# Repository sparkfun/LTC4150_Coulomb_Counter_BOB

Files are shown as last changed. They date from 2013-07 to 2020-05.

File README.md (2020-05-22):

SparkFun Coulomb Counter Breakout - LTC4150
===========================

SparkFun Coulomb Counter Breakout - LTC4150 (https://www.sparkfun.com/products/12052)

_[SparkFun Coulomb Counter Breakout - LTC4150 [ BOB-12052 ]](https://www.sparkfun.com/products/12052)_

*Breakout board for the Linear Tech LTC4150 Coulomb Counter (bidirectional current sensor / battery gauge)*

The LTC4150 Coulomb Counter monitors current passing through it (from the IN header or JST connector to the OUT header). Each time 0.1707 mAh passes through the device, the INT pin will pulse low. Or to put it another way, the INT pin will pulse low 5859 times for each Ah that passes through it.

There is also a POL pin that you can check each time INT goes low. POL will be L for current going from IN to OUT, and H for current going from OUT to IN (battery charging).

If you count these pulses and add or subtract from a total depending on the POL signal, you can keep accurate track of the state of a battery connected to the board.

The Coulomb Counter can accommodate power supplies up to 8.5V and up to 1A.

Quickstart (Arduino)
-------------------

* Configure the jumpers:

    If you're connecting the Coulomb Counter to a 5V system, leave solder jumpers SJ2 and SJ3 (on the bottom of the board) open (the default).

    If you're connecting the Coulomb Counter to a 3.3V system, close both SJ2 and SJ3.

* Hook up the I/O lines:

    Connect VIO to your system's VCC (3.3V or 5V) line.

    Connect GND to your system's ground line.

    Connect INT to your system's interrupt input (D3)

    Connect POL to an I/O pin (D4)

* Connect the IN header or the JST connector to your power source (up to 8.5V)

* Connect the OUT header to your system's power input

* Upload and run the Coulomb_Interrupt example code from this repository, and open a Serial Monitor set to 9600 bps. It should display a hello message and begin giving you periodic updates about the battery state. (See the comments for instructions on customizing it for your exact battery.)

See the [Hookup Guide](https://learn.sparkfun.com/tutorials/ltc4150-coulomb-counter-hookup-guide) for much more information.

Have fun! -Your friends at SparkFun

Repository Contents
-------------------

* **/Documentation** - Data sheets, additional product information
* **/Hardware** - Eagle design files (.brd, .sch)
* **/Production** - Production panel files (.brd)
* **/Software** - Arduino example code

Documentation
--------------

* **[Hookup Guide](https://learn.sparkfun.com/tutorials/ltc4150-coulomb-counter-hookup-guide)** - Basic hookup guide

License Information
-------------------

This product is _**open source**_! 

Please review the LICENSE.md file for license information. 

If you have any questions or concerns on licensing, please contact technical support on our [SparkFun forums](https://forum.sparkfun.com/viewforum.php?f=152).

Distributed as-is; no warranty is given.

- Your friends at SparkFun.

_<COLLABORATION CREDIT>_

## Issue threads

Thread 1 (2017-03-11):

Invalid library found

AusUser5, 2017-03-11:
Adding the zip to Ardunino 1.6.11 failed.

Adding library manually showed error "invalid library found"

bboyho, 2020-05-22:
Hi,

Sorry for the delay in reply. I came across your question when browsing our issues. It looks like you are trying to add the example code to your Arduino library. I do not believe that will work (as you have seen) because the example code is not structured as a library.

If you are still wondering, you just need to unzip the files and open the individual &#42;.ino examples in the Arduino IDE.

Closed 2020-05-22.

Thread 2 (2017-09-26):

Interrupt example code doesn't work on Pro Micro

chrise96, 2017-09-26:

mgrusin, 2017-10-18:
Hi there, did you solve your issue? If you found the solution, it's good karma to post it here for us (and others) to see. Thanks!

chrise96, 2017-10-18:
Hi Mike,
I haven't figured this issue out yet. I'm happy you are still active! I cant make this one open but made some edits to the post.

The issue is that the interrupt example takes a long time to show an interrupt message and gives me incorrect values of mA:
Normal with polling:
mAh: 1998.98 soc: 99.95% time: 367.73s mA: 1.67
mAh: 1998.81 soc: 99.94% time: 374.93s mA: 1.64
mAh: 1998.63 soc: 99.93% time: 363.59s mA: 1.69

With interrupt example (with same external microcontroller and external battery connected):
mAh: 1998.98 soc: 99.95% time: 1267.73s mA: 0.30 (something like this, dont have the log)
mAh: 1998.81 soc: 99.94% time: 1274.93s mA: 0.30 (something like this, dont have the log)

Closed 2017-10-18.

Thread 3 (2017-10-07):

multiple invalid libraries found

joebataz, 2017-10-07:

joebataz, 2017-10-07:
I am getting a long list of invalid library found in <path to arduino libraries> I  have just started up programming (or trying to) again after a couple of years. I am also getting
Documents/Arduino/libraries/FastLED/FastLED.h:12:2: warning: #warning FastLED version 3.001.000 (Not really a warning, just telling you here.) [-Wcpp]
 #warning FastLED version 3.001.000  (Not really a warning, just telling you here.)
I don't understand if this is an error or not. How do I get rid of these errors/warnings/whatever?

THANKS to whoever gets me this answer, I REALLY appreciate it!
joe b

mgrusin, 2017-10-09:
If you haven't used it in a while, recent updates to Arduino may have rendered old libraries invalid. I would try opening sketch/include library/manage libraries, and see if any of them can be automatically updated. If they can't you may have to delete them and reinstall them manually. If you're stuck, our tech support department can help: https://www.sparkfun.com/technical_assistance. Hope this helps, good luck!

joebataz, 2017-10-09:
Thanks Mike.
It resolved down to 5 problem libraries and one bad nano. Got new libraries where needed and fired up old reliable Mega and all is well now. Did a little refresher coding and looks like I actually remember how to code!

Thanks again!!

Joe B
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

mgrusin, 2017-10-09:
That's GREAT to hear! Have fun and let us know if you have further questions (or want to show off what you're making! ;)

Closed 2017-10-09.

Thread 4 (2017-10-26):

Three Coulomb counters with all different values

arrowmax08, 2017-10-26:
Hi,

I tested three LTC4150's that all print different values.

The first value will be incorrect, because we have no previous start time to compare the delay between interrupts with. The INT pin will pulse low every time 0.614 coulombs passes through the device. So you can say that all coulomb counters with the same setup must print very similar values.

With two AA batteries connected to the IN port of the Coulomb counter I get around the following values:

Coulomb counter 1: prints "1.30 mA"
Coulomb counter 2: prints "2.15 mA"
Coulomb counter 3: prints "1.80 mA"

Are they not calibrated right?

mgrusin, 2017-10-26:
Good question and interesting results.

To be honest, determining instantaneous power consumption from the timing of the coulomb interrupt, especially for low currents like the above, is a bit of a parlor trick. Even though the number of INT pulses over time should be accurate, calculating instantaneous power consumption by measuring the time between them is subject to numerous measurement and rounding errors (especially if you're using the polled code rather than interrupt-driven). Your test setup is also important; it's better to measure a fixed resistor (the same one for all three boards) than a dynamic load like a processor or LED; and to use a fixed linear power source rather than a battery, which can change voltage during use and recovery. And you're right; I've never looked at the statistics for a large number of counters, but there could be manufacturing variations in the chips and sense resistors, etc.

 If you absolutely require consistent numbers between all your boards, the best solution is always to calibrate them individually using the best test setup you can manage. This usually means a fixed (linear) power source and load resistor.  Per the above I'd measure a large number of INT pulses over time rather than the individual timing. You'd then apply the results to the individual bits of software doing the reading. This is often not worth the trouble for a few percent difference, but if one or more of your boards is obviously misbehaving please do contact our tech support department for replacement.

Hope this helps, thanks for asking!

Closed 2018-07-06.

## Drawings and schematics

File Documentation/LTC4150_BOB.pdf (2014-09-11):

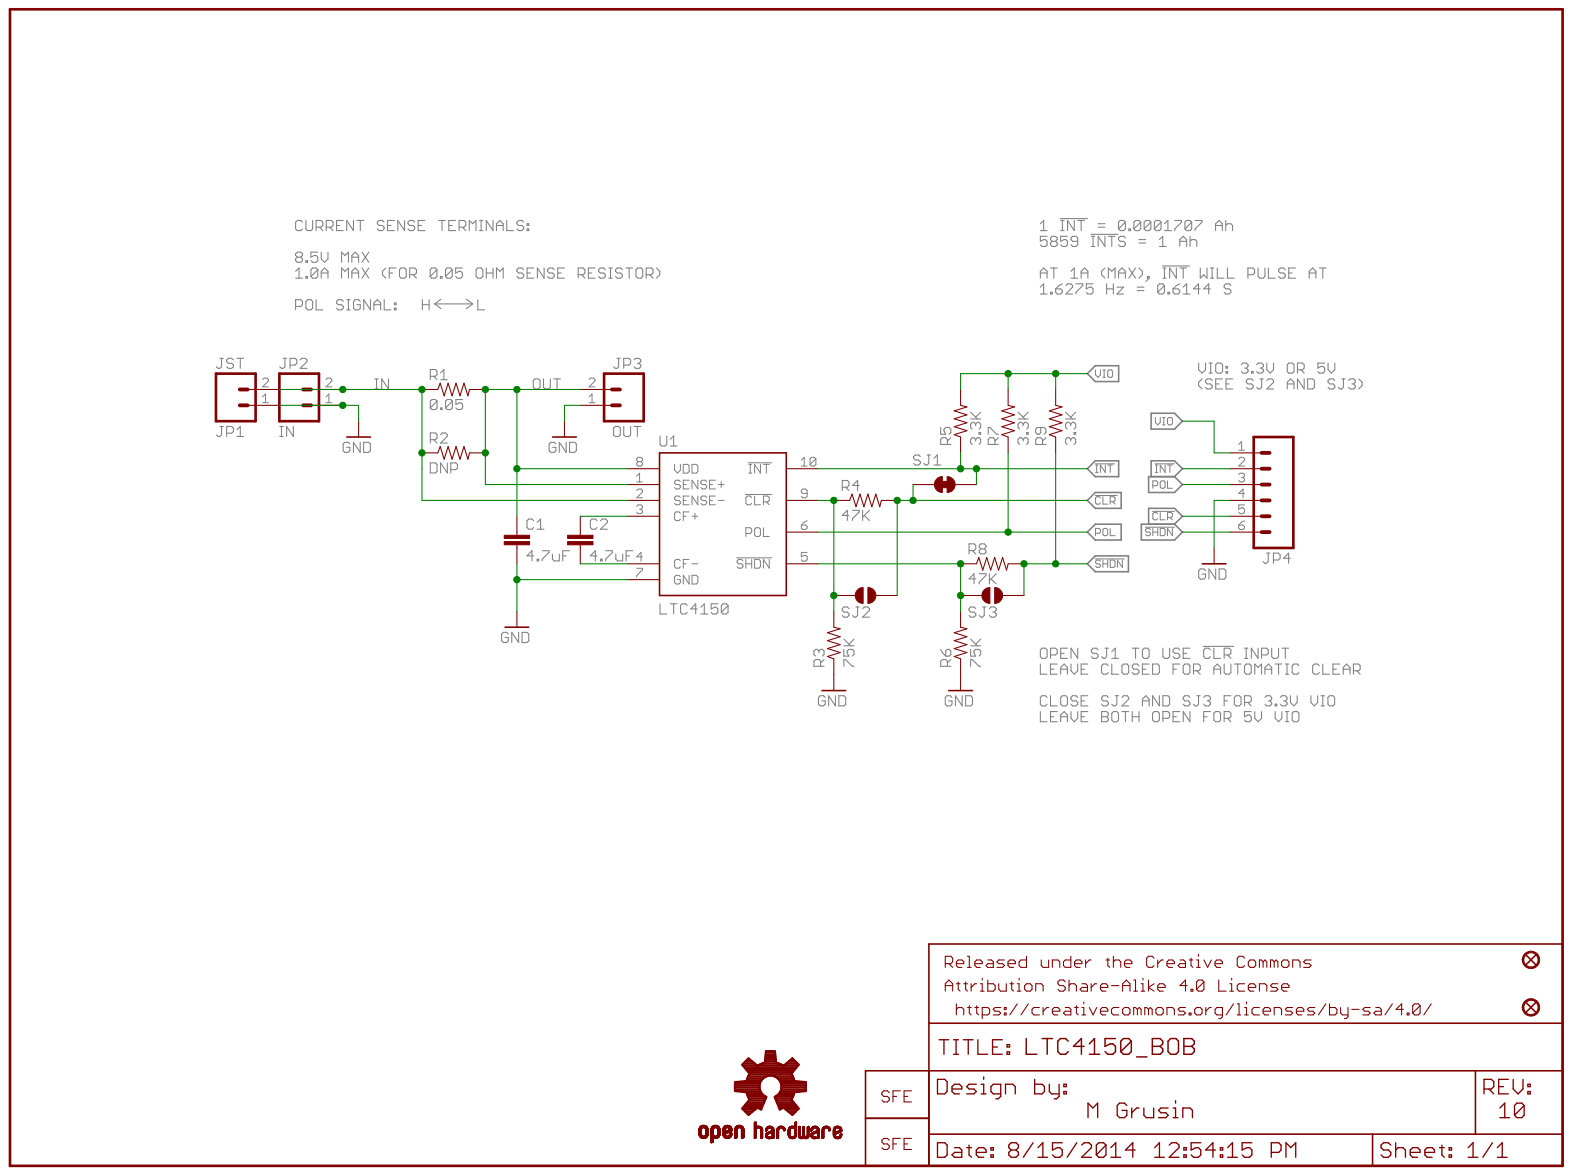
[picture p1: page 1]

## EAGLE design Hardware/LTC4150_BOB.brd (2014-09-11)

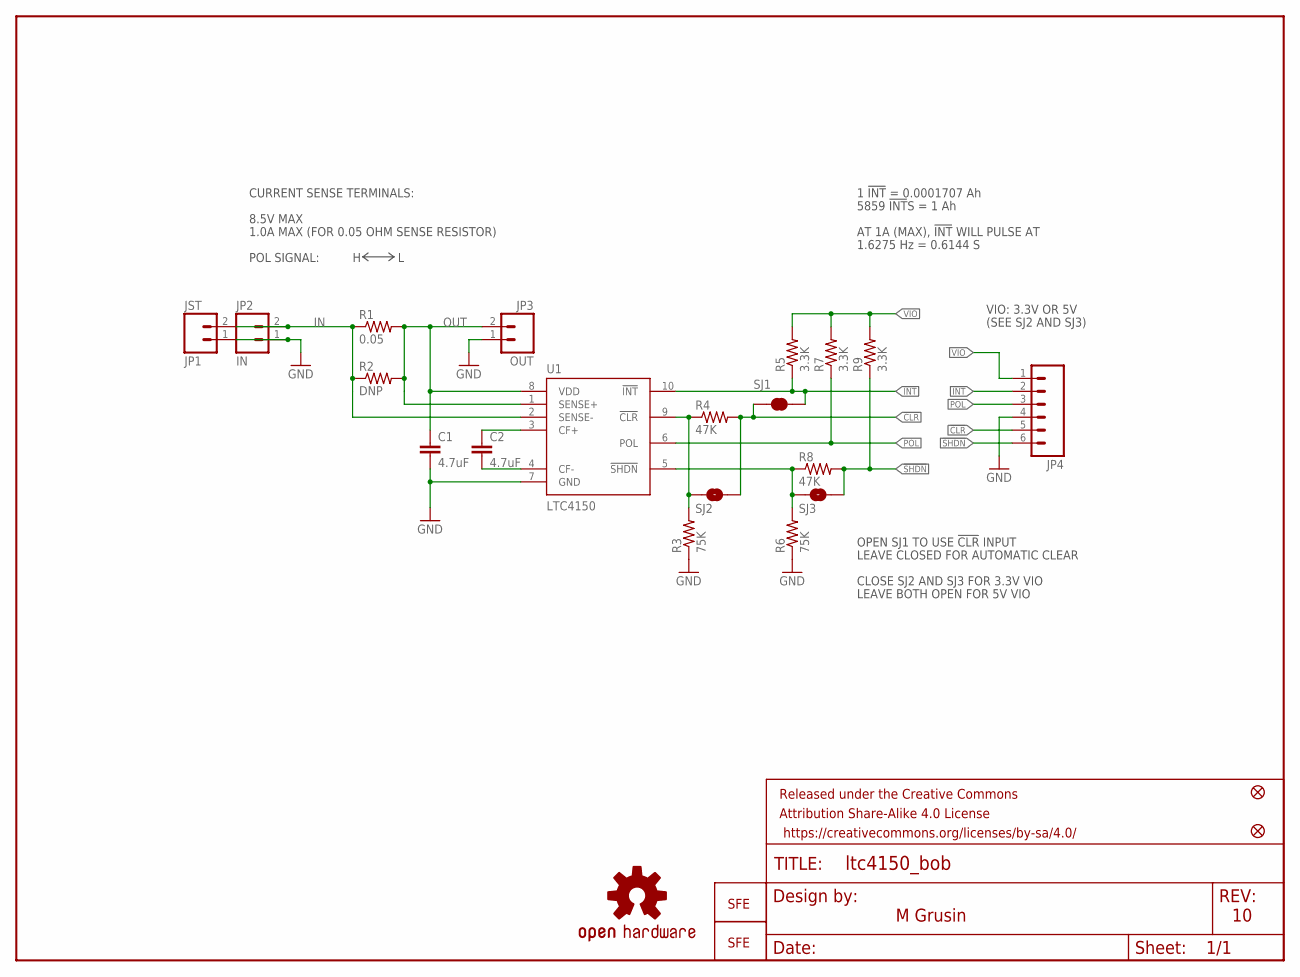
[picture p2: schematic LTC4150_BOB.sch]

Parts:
C1, C2: 4.7uF; 0603-CAP
FID1, FID2: FIDUCIAL1X2; FIDUCIAL-1X2
FRAME1: FRAME-LETTER; CREATIVE_COMMONS
JP1: JST; JST-2-SMD
JP2: IN; 1X02
JP3: OUT; 1X02
JP4: M06SIP; 1X06
LOGO1: OSHW-LOGOS; OSHW-LOGO-S
LOGO2: LOGO-SFENW2; SFE-NEW-WEB
LOGO3: LOGO-SFESK; SFE-LOGO-FLAME
R1: 0.05; 1206
R2: DNP; AXIAL-0.3
R3, R6: 75K; 0603-RES
R4, R8: 47K; 0603-RES
R5, R7, R9: 3.3K; 0603-RES
SJ1: SOLDERJUMPERNC; SJ_2S
SJ2, SJ3: SOLDERJUMPERNO; SJ_2S-NO
U1: LTC4150; MSOP10

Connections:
!CLR!: JP4.5, R4.2, SJ1.1, SJ2.2
!INT!: JP4.2, R5.1, SJ1.2, U1.10 (!INT!)
!SHDN!: JP4.6, R8.2, R9.1, SJ3.2
GND: C1.2, JP1.1 (2), JP2.1, JP3.1, JP4.4, R3.1, R6.1, U1.7 (GND)
IN: JP1.2 (1), JP2.2, R1.1, R2.P$1 (1), U1.2 (SENSE-)
unnamed: R3.2, R4.1, SJ2.1, U1.9 (!CLR!)
unnamed: C2.1, U1.3 (CF+)
unnamed: C2.2, U1.4 (CF-)
unnamed: R6.2, R8.1, SJ3.1, U1.5 (!SHDN!)
OUT: C1.1, JP3.2, R1.2, R2.P$2 (2), U1.1 (SENSE+), U1.8 (VDD)
POL: JP4.3, R7.1, U1.6 (POL)
VIO: JP4.1, R5.2, R7.2, R9.2

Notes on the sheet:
M Grusin
CLOSE SJ2 AND SJ3 FOR 3.3V VIO
CURRENT SENSE TERMINALS:
LEAVE BOTH OPEN FOR 5V VIO
AT 1A (MAX), !INT! WILL PULSE AT
1.6275 Hz = 0.6144 S
1 !INT! = 0.0001707 Ah
5859 !INT!S = 1 Ah
OPEN SJ1 TO USE !CLR! INPUT
1.0A MAX (FOR 0.05 OHM SENSE RESISTOR)
VIO: 3.3V OR 5V
(SEE SJ2 AND SJ3)
LEAVE CLOSED FOR AUTOMATIC CLEAR
8.5V MAX
POL SIGNAL:

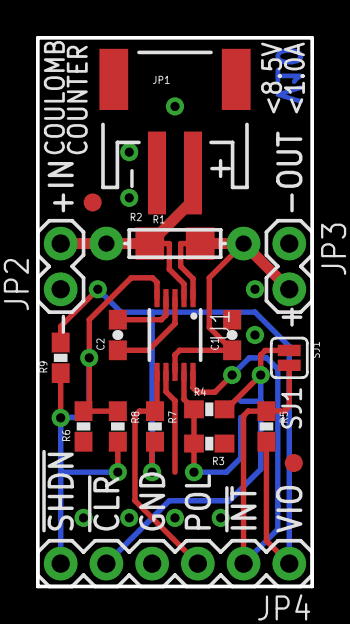
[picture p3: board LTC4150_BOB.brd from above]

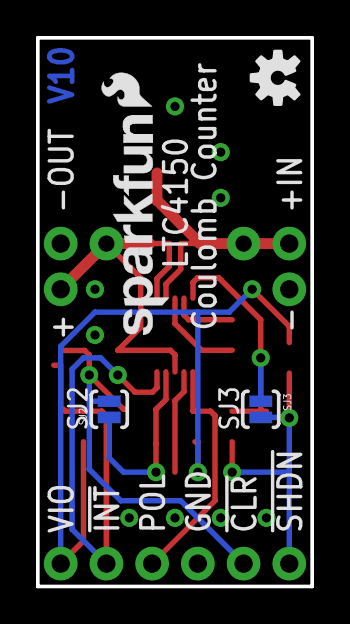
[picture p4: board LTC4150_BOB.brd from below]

Board: 2 copper layers, 15.2 x 30.5 mm, 25 parts (5 on the bottom side), 12 nets.

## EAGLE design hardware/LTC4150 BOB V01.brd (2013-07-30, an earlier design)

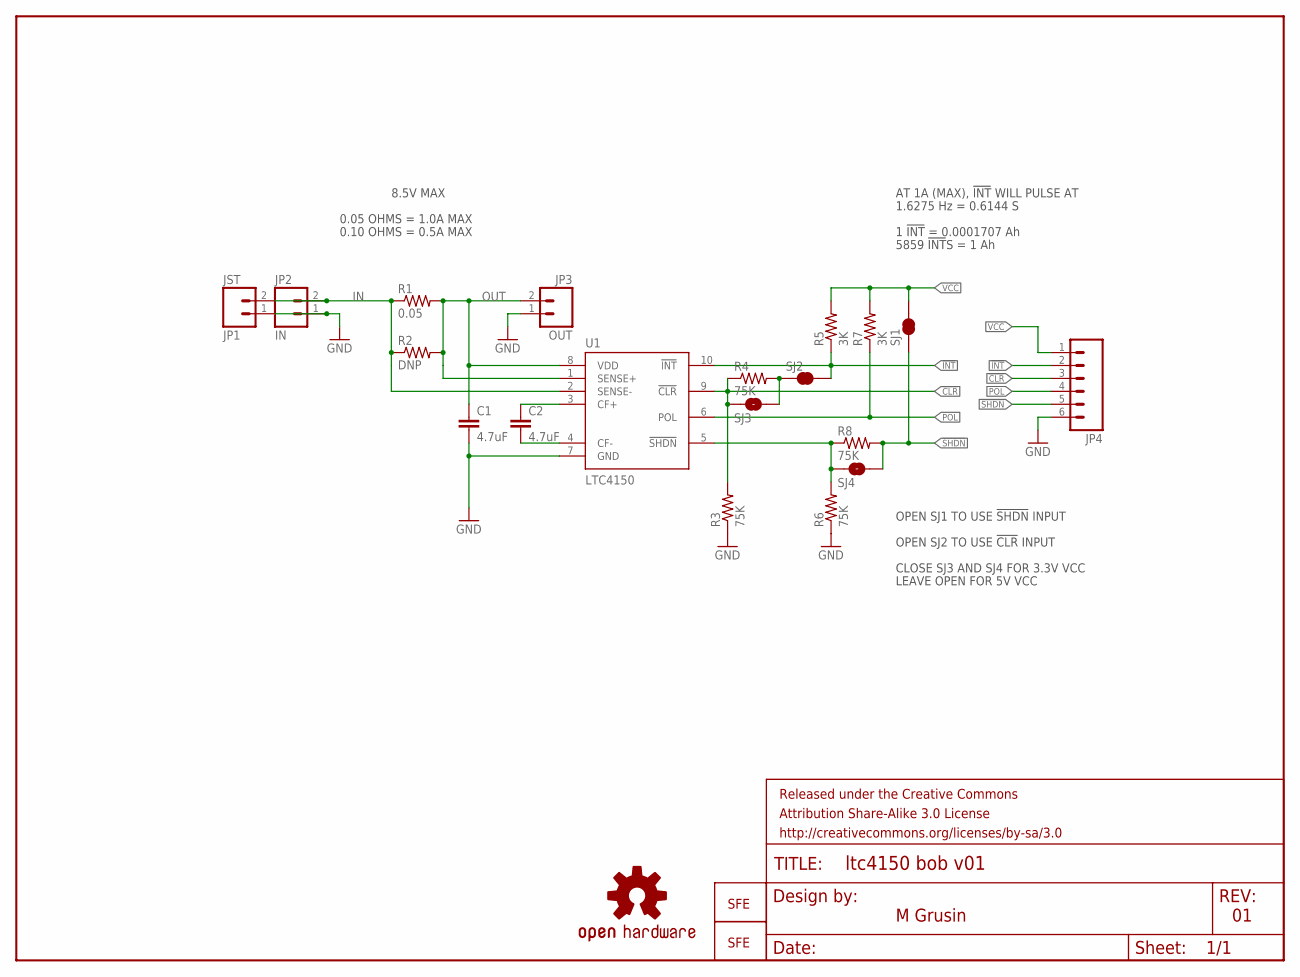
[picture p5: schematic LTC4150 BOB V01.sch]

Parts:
C1, C2: 4.7uF; 0603-CAP
FRAME1: FRAME-LETTER; CREATIVE_COMMONS
JP1: JST; JST-2-SMD
JP2: IN; 1X02
JP3: OUT; 1X02
JP4: M06SIP; 1X06
LOGO1: OSHW-LOGOS; OSHW-LOGO-S
LOGO2: LOGO-SFENW2; SFE-NEW-WEB
LOGO3: LOGO-SFESK; SFE-LOGO-FLAME
R1: 0.05; 0805
R2: DNP; AXIAL-0.3
R3, R4, R6, R8: 75K; 0603-RES
R5, R7: 3K; 0603-RES
SJ1, SJ2: SOLDERJUMPERNC; SJ_2S
SJ3, SJ4: SOLDERJUMPERNO; SJ_2S-NO
U1: LTC4150; MSOP10

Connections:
!CLR!: JP4.3, R3.2, R4.1, SJ3.1, U1.9 (!CLR!)
!INT!: JP4.2, R5.1, SJ2.2, U1.10 (!INT!)
!SHDN!: JP4.5, R8.2, SJ1.2, SJ4.2
GND: C1.2, JP1.1 (2), JP2.1, JP3.1, JP4.6, R3.1, R6.1, U1.7 (GND)
IN: JP1.2 (1), JP2.2, R1.1, R2.P$1 (1), U1.2 (SENSE-)
unnamed: R4.2, SJ2.1, SJ3.2
unnamed: C2.1, U1.3 (CF+)
unnamed: C2.2, U1.4 (CF-)
unnamed: R6.2, R8.1, SJ4.1, U1.5 (!SHDN!)
OUT: C1.1, JP3.2, R1.2, R2.P$2 (2), U1.1 (SENSE+), U1.8 (VDD)
POL: JP4.4, R7.1, U1.6 (POL)
VCC: JP4.1, R5.2, R7.2, SJ1.1

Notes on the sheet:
M Grusin
CLOSE SJ3 AND SJ4 FOR 3.3V VCC
OPEN SJ1 TO USE !SHDN! INPUT
8.5V MAX
LEAVE OPEN FOR 5V VCC
AT 1A (MAX), !INT! WILL PULSE AT
1.6275 Hz = 0.6144 S
1 !INT! = 0.0001707 Ah
5859 !INT!S = 1 Ah
OPEN SJ2 TO USE !CLR! INPUT
0.05 OHMS = 1.0A MAX
0.10 OHMS = 0.5A MAX

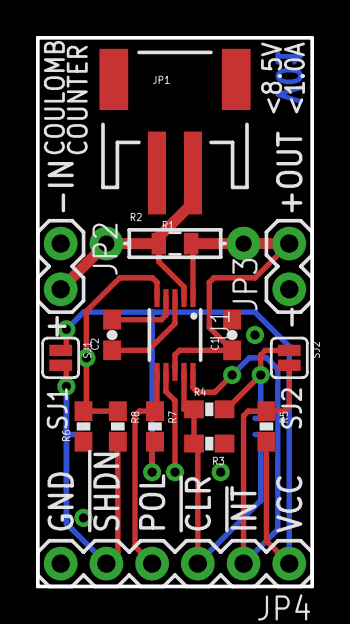
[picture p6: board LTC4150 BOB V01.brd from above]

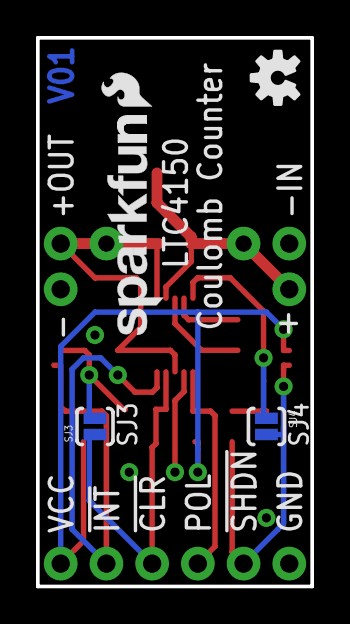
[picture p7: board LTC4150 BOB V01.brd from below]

Board: 2 copper layers, 15.2 x 30.5 mm, 23 parts (5 on the bottom side), 12 nets.

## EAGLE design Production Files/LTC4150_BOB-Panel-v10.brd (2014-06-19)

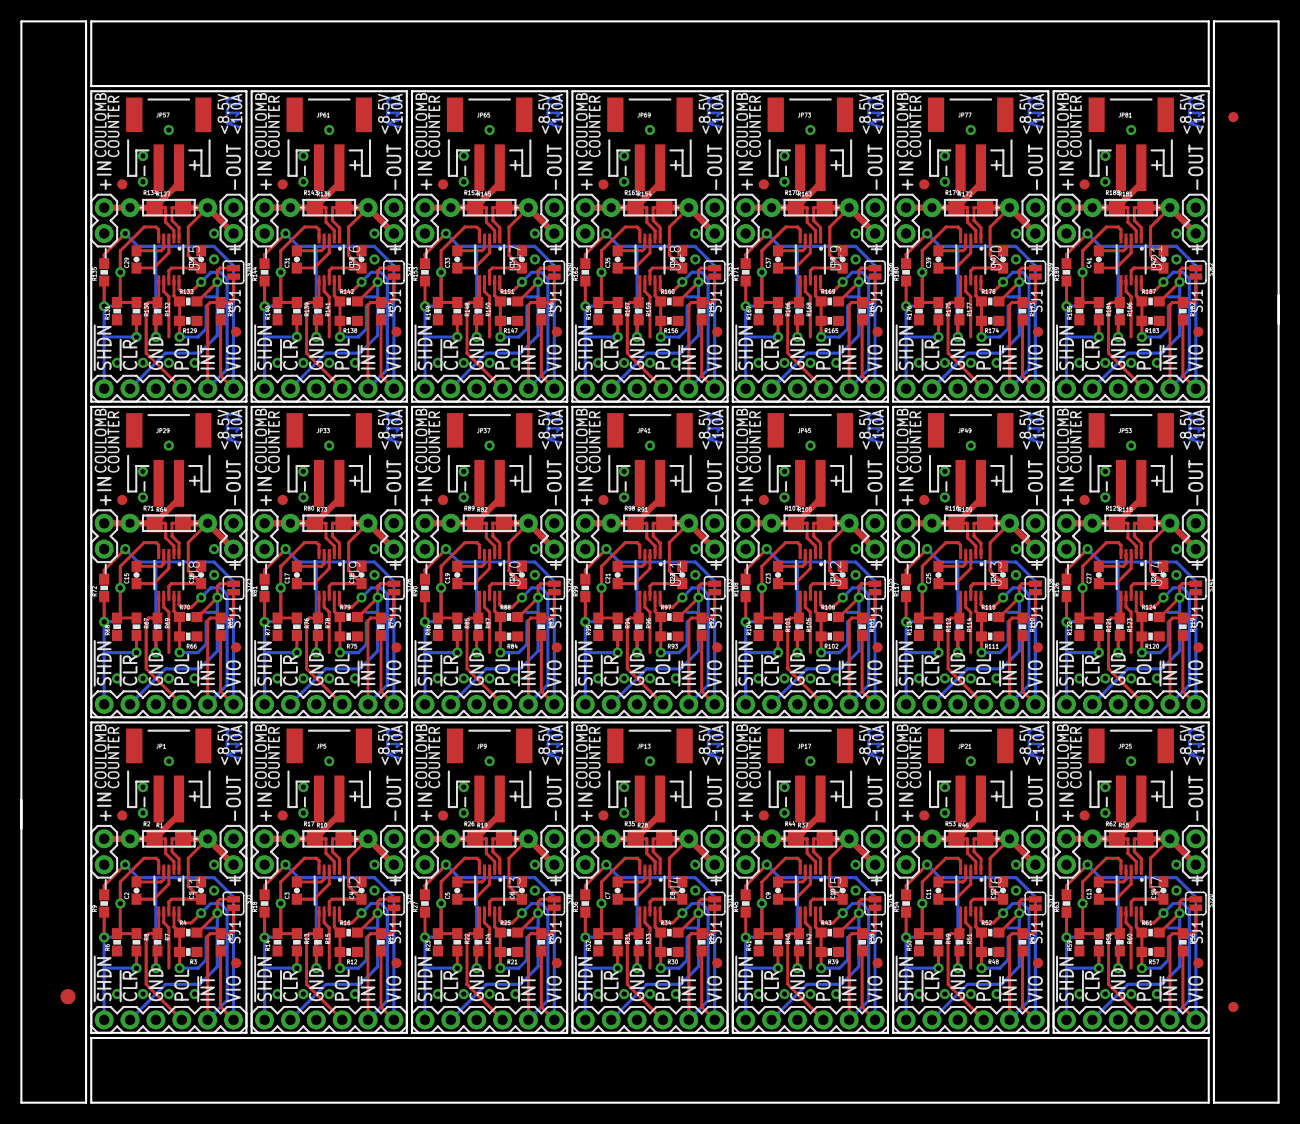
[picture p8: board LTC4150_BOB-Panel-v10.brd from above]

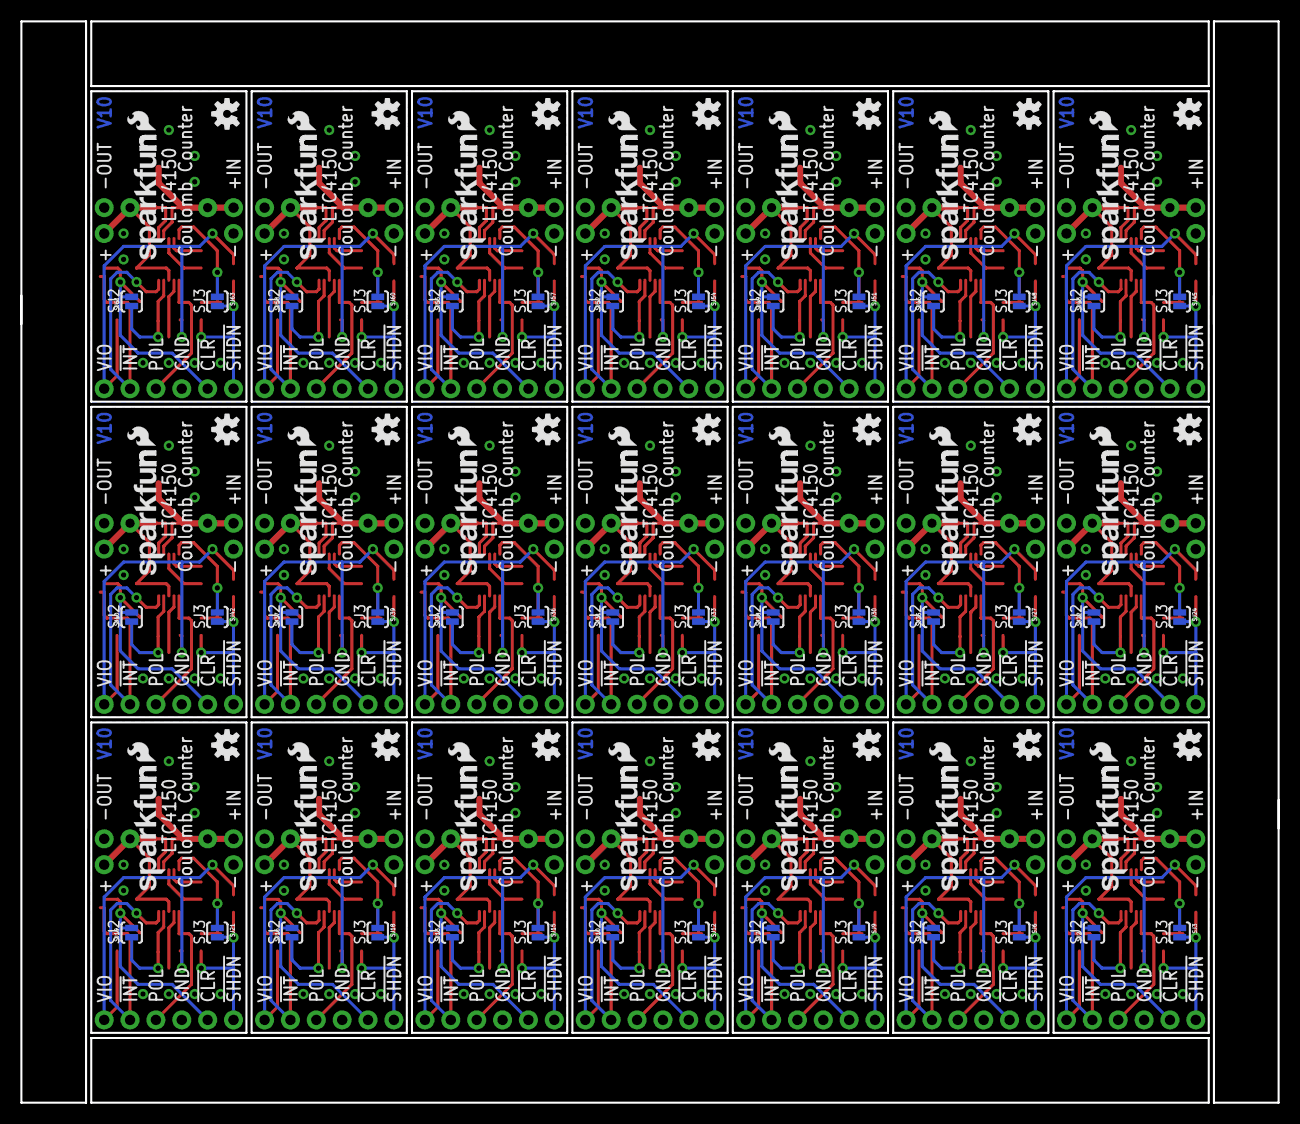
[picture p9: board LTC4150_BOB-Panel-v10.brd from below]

Board: 2 copper layers, 123.4 x 106.2 mm, 507 parts (105 on the bottom side), 252 nets.

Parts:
C1, C2, C3, C4, C5, C6, C7, C8, C9, C10, C11, C12, C13, C14, C15, C16, C17, C18, C19, C20, C21, C22, C23, C24, C25, C26, C27, C28, C29, C30, C31, C32, C33, C34, C35, C36, C37, C38, C39, C40, C41, C42: 4.7uF; 0603-CAP
E$1: FIDUCIAL-1.5X3
E$4, E$5: FIDUCIAL-1X2
FID1, FID2, FID3, FID4, FID5, FID6, FID7, FID8, FID9, FID10, FID11, FID12, FID13, FID14, FID15, FID16, FID17, FID18, FID19, FID20, FID21, FID22, FID23, FID24, FID25, FID26, FID27, FID28, FID29, FID30, FID31, FID32, FID33, FID34, FID35, FID36, FID37, FID38, FID39, FID40, FID41, FID42: FIDUCIAL1X2; FIDUCIAL-1X2
JP1, JP5, JP9, JP13, JP17, JP21, JP25, JP29, JP33, JP37, JP41, JP45, JP49, JP53, JP57, JP61, JP65, JP69, JP73, JP77, JP81: JST; JST-2-SMD
JP2, JP6, JP10, JP14, JP18, JP22, JP26, JP30, JP34, JP38, JP42, JP46, JP50, JP54, JP58, JP62, JP66, JP70, JP74, JP78, JP82: IN; 1X02
JP3, JP7, JP11, JP15, JP19, JP23, JP27, JP31, JP35, JP39, JP43, JP47, JP51, JP55, JP59, JP63, JP67, JP71, JP75, JP79, JP83: OUT; 1X02
JP4, JP8, JP12, JP16, JP20, JP24, JP28, JP32, JP36, JP40, JP44, JP48, JP52, JP56, JP60, JP64, JP68, JP72, JP76, JP80, JP84: 1X06
LOGO1, LOGO5, LOGO8, LOGO11, LOGO14, LOGO17, LOGO20, LOGO23, LOGO26, LOGO29, LOGO32, LOGO35, LOGO38, LOGO41, LOGO44, LOGO47, LOGO50, LOGO53, LOGO56, LOGO59, LOGO62: OSHW-LOGOS; OSHW-LOGO-S
LOGO2, LOGO6, LOGO9, LOGO12, LOGO15, LOGO18, LOGO21, LOGO24, LOGO27, LOGO30, LOGO33, LOGO36, LOGO39, LOGO42, LOGO45, LOGO48, LOGO51, LOGO54, LOGO57, LOGO60, LOGO63: LOGO-SFENW2; SFE-NEW-WEB
LOGO3, LOGO4, LOGO7, LOGO10, LOGO13, LOGO16, LOGO19, LOGO22, LOGO25, LOGO28, LOGO31, LOGO34, LOGO37, LOGO40, LOGO43, LOGO46, LOGO49, LOGO52, LOGO55, LOGO58, LOGO61: LOGO-SFESK; SFE-LOGO-FLAME
R1, R10, R19, R28, R37, R46, R55, R64, R73, R82, R91, R100, R109, R118, R127, R136, R145, R154, R163, R172, R181: 0.05; 1206
R2, R17, R26, R35, R44, R53, R62, R71, R80, R89, R98, R107, R116, R125, R134, R143, R152, R161, R170, R179, R188: DNP; AXIAL-0.3
R3, R6, R12, R14, R21, R23, R30, R32, R39, R41, R48, R50, R57, R59, R66, R68, R75, R77, R84, R86, R93, R95, R102, R104, R111, R113, R120, R122, R129, R131, R138, R140, R147, R149, R156, R158, R165, R167, R174, R176, R183, R185: 75K; 0603-RES
R4, R8, R13, R16, R22, R25, R31, R34, R40, R43, R49, R52, R58, R61, R67, R70, R76, R79, R85, R88, R94, R97, R103, R106, R112, R115, R121, R124, R130, R133, R139, R142, R148, R151, R157, R160, R166, R169, R175, R178, R184, R187: 47K; 0603-RES
R5, R7, R9, R11, R15, R18, R20, R24, R27, R29, R33, R36, R38, R42, R45, R47, R51, R54, R56, R60, R63, R65, R69, R72, R74, R78, R81, R83, R87, R90, R92, R96, R99, R101, R105, R108, R110, R114, R117, R119, R123, R126, R128, R132, R135, R137, R141, R144, R146, R150, R153, R155, R159, R162, R164, R168, R171, R173, R177, R180, R182, R186, R189: 3.3K; 0603-RES
SJ1, SJ5, SJ8, SJ11, SJ14, SJ17, SJ20, SJ23, SJ26, SJ29, SJ32, SJ35, SJ38, SJ41, SJ44, SJ47, SJ50, SJ53, SJ56, SJ59, SJ62: SJ_2S
SJ2, SJ3, SJ4, SJ6, SJ7, SJ9, SJ10, SJ12, SJ13, SJ15, SJ16, SJ18, SJ19, SJ21, SJ22, SJ24, SJ25, SJ27, SJ28, SJ30, SJ31, SJ33, SJ34, SJ36, SJ37, SJ39, SJ40, SJ42, SJ43, SJ45, SJ46, SJ48, SJ49, SJ51, SJ52, SJ54, SJ55, SJ57, SJ58, SJ60, SJ61, SJ63: SJ_2S-NO
U1, U2, U3, U4, U5, U6, U7, U8, U9, U10, U11, U12, U13, U14, U15, U16, U17, U18, U19, U20, U21: LTC4150; MSOP10

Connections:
!CLR!: JP4.5, R4.2, SJ1.1, SJ2.2
!CLR!1: JP8.5, R16.2, SJ4.2, SJ5.1
!CLR!2: JP12.5, R25.2, SJ7.2, SJ8.1
!CLR!3: JP16.5, R34.2, SJ10.2, SJ11.1
!CLR!4: JP20.5, R43.2, SJ13.2, SJ14.1
!CLR!5: JP24.5, R52.2, SJ16.2, SJ17.1
!CLR!6: JP28.5, R61.2, SJ19.2, SJ20.1
!CLR!7: JP32.5, R70.2, SJ22.2, SJ23.1
!CLR!8: JP36.5, R79.2, SJ25.2, SJ26.1
!CLR!9: JP40.5, R88.2, SJ28.2, SJ29.1
!CLR!10: JP44.5, R97.2, SJ31.2, SJ32.1
!CLR!11: JP48.5, R106.2, SJ34.2, SJ35.1
!CLR!12: JP52.5, R115.2, SJ37.2, SJ38.1
!CLR!13: JP56.5, R124.2, SJ40.2, SJ41.1
!CLR!14: JP60.5, R133.2, SJ43.2, SJ44.1
!CLR!15: JP64.5, R142.2, SJ46.2, SJ47.1
!CLR!16: JP68.5, R151.2, SJ49.2, SJ50.1
!CLR!17: JP72.5, R160.2, SJ52.2, SJ53.1
!CLR!18: JP76.5, R169.2, SJ55.2, SJ56.1
!CLR!19: JP80.5, R178.2, SJ58.2, SJ59.1
!CLR!20: JP84.5, R187.2, SJ61.2, SJ62.1
!INT!: JP4.2, R5.1, SJ1.2, U1.10
!INT!1: JP8.2, R11.1, SJ5.2, U2.10
!INT!2: JP12.2, R20.1, SJ8.2, U3.10
!INT!3: JP16.2, R29.1, SJ11.2, U4.10
!INT!4: JP20.2, R38.1, SJ14.2, U5.10
!INT!5: JP24.2, R47.1, SJ17.2, U6.10
!INT!6: JP28.2, R56.1, SJ20.2, U7.10
!INT!7: JP32.2, R65.1, SJ23.2, U8.10
!INT!8: JP36.2, R74.1, SJ26.2, U9.10
!INT!9: JP40.2, R83.1, SJ29.2, U10.10
!INT!10: JP44.2, R92.1, SJ32.2, U11.10
!INT!11: JP48.2, R101.1, SJ35.2, U12.10
!INT!12: JP52.2, R110.1, SJ38.2, U13.10
!INT!13: JP56.2, R119.1, SJ41.2, U14.10
!INT!14: JP60.2, R128.1, SJ44.2, U15.10
!INT!15: JP64.2, R137.1, SJ47.2, U16.10
!INT!16: JP68.2, R146.1, SJ50.2, U17.10
!INT!17: JP72.2, R155.1, SJ53.2, U18.10
!INT!18: JP76.2, R164.1, SJ56.2, U19.10
!INT!19: JP80.2, R173.1, SJ59.2, U20.10
!INT!20: JP84.2, R182.1, SJ62.2, U21.10
!SHDN!: JP4.6, R8.2, R9.1, SJ3.2
!SHDN!1: JP8.6, R13.2, R18.1, SJ6.2
!SHDN!2: JP12.6, R22.2, R27.1, SJ9.2
!SHDN!3: JP16.6, R31.2, R36.1, SJ12.2
!SHDN!4: JP20.6, R40.2, R45.1, SJ15.2
!SHDN!5: JP24.6, R49.2, R54.1, SJ18.2
!SHDN!6: JP28.6, R58.2, R63.1, SJ21.2
!SHDN!7: JP32.6, R67.2, R72.1, SJ24.2
!SHDN!8: JP36.6, R76.2, R81.1, SJ27.2
!SHDN!9: JP40.6, R85.2, R90.1, SJ30.2
!SHDN!10: JP44.6, R94.2, R99.1, SJ33.2
!SHDN!11: JP48.6, R103.2, R108.1, SJ36.2
!SHDN!12: JP52.6, R112.2, R117.1, SJ39.2
!SHDN!13: JP56.6, R121.2, R126.1, SJ42.2
!SHDN!14: JP60.6, R130.2, R135.1, SJ45.2
!SHDN!15: JP64.6, R139.2, R144.1, SJ48.2
!SHDN!16: JP68.6, R148.2, R153.1, SJ51.2
!SHDN!17: JP72.6, R157.2, R162.1, SJ54.2
!SHDN!18: JP76.6, R166.2, R171.1, SJ57.2
!SHDN!19: JP80.6, R175.2, R180.1, SJ60.2
!SHDN!20: JP84.6, R184.2, R189.1, SJ63.2
GND: C1.2, JP1.1, JP2.1, JP3.1, JP4.4, R3.1, R6.1, U1.7
GND1: C4.2, JP5.1, JP6.1, JP7.1, JP8.4, R12.1, R14.1, U2.7
GND2: C6.2, JP9.1, JP10.1, JP11.1, JP12.4, R21.1, R23.1, U3.7
GND3: C8.2, JP13.1, JP14.1, JP15.1, JP16.4, R30.1, R32.1, U4.7
GND4: C10.2, JP17.1, JP18.1, JP19.1, JP20.4, R39.1, R41.1, U5.7
GND5: C12.2, JP21.1, JP22.1, JP23.1, JP24.4, R48.1, R50.1, U6.7
GND6: C14.2, JP25.1, JP26.1, JP27.1, JP28.4, R57.1, R59.1, U7.7
GND7: C16.2, JP29.1, JP30.1, JP31.1, JP32.4, R66.1, R68.1, U8.7
GND8: C18.2, JP33.1, JP34.1, JP35.1, JP36.4, R75.1, R77.1, U9.7
GND9: C20.2, JP37.1, JP38.1, JP39.1, JP40.4, R84.1, R86.1, U10.7
GND10: C22.2, JP41.1, JP42.1, JP43.1, JP44.4, R93.1, R95.1, U11.7
GND11: C24.2, JP45.1, JP46.1, JP47.1, JP48.4, R102.1, R104.1, U12.7
GND12: C26.2, JP49.1, JP50.1, JP51.1, JP52.4, R111.1, R113.1, U13.7
GND13: C28.2, JP53.1, JP54.1, JP55.1, JP56.4, R120.1, R122.1, U14.7
GND14: C30.2, JP57.1, JP58.1, JP59.1, JP60.4, R129.1, R131.1, U15.7
GND15: C32.2, JP61.1, JP62.1, JP63.1, JP64.4, R138.1, R140.1, U16.7
GND16: C34.2, JP65.1, JP66.1, JP67.1, JP68.4, R147.1, R149.1, U17.7
GND17: C36.2, JP69.1, JP70.1, JP71.1, JP72.4, R156.1, R158.1, U18.7
GND18: C38.2, JP73.1, JP74.1, JP75.1, JP76.4, R165.1, R167.1, U19.7
GND19: C40.2, JP77.1, JP78.1, JP79.1, JP80.4, R174.1, R176.1, U20.7
GND20: C42.2, JP81.1, JP82.1, JP83.1, JP84.4, R183.1, R185.1, U21.7
IN: JP1.2, JP2.2, R1.1, R2.P$1, U1.2
IN1: JP5.2, JP6.2, R10.1, R17.P$1, U2.2
IN2: JP9.2, JP10.2, R19.1, R26.P$1, U3.2
IN3: JP13.2, JP14.2, R28.1, R35.P$1, U4.2
IN4: JP17.2, JP18.2, R37.1, R44.P$1, U5.2
IN5: JP21.2, JP22.2, R46.1, R53.P$1, U6.2
IN6: JP25.2, JP26.2, R55.1, R62.P$1, U7.2
IN7: JP29.2, JP30.2, R64.1, R71.P$1, U8.2
IN8: JP33.2, JP34.2, R73.1, R80.P$1, U9.2
IN9: JP37.2, JP38.2, R82.1, R89.P$1, U10.2
IN10: JP41.2, JP42.2, R91.1, R98.P$1, U11.2
IN11: JP45.2, JP46.2, R100.1, R107.P$1, U12.2
IN12: JP49.2, JP50.2, R109.1, R116.P$1, U13.2
IN13: JP53.2, JP54.2, R118.1, R125.P$1, U14.2
IN14: JP57.2, JP58.2, R127.1, R134.P$1, U15.2
IN15: JP61.2, JP62.2, R136.1, R143.P$1, U16.2
IN16: JP65.2, JP66.2, R145.1, R152.P$1, U17.2
IN17: JP69.2, JP70.2, R154.1, R161.P$1, U18.2
IN18: JP73.2, JP74.2, R163.1, R170.P$1, U19.2
IN19: JP77.2, JP78.2, R172.1, R179.P$1, U20.2
IN20: JP81.2, JP82.2, R181.1, R188.P$1, U21.2
unnamed: R3.2, R4.1, SJ2.1, U1.9
unnamed: C3.1, U2.3
unnamed: C2.1, U1.3
unnamed: C2.2, U1.4
unnamed: C3.2, U2.4
unnamed: R13.1, R14.2, SJ6.1, U2.5
unnamed: R12.2, R16.1, SJ4.1, U2.9
unnamed: C5.1, U3.3
unnamed: R6.2, R8.1, SJ3.1, U1.5
unnamed: C5.2, U3.4
unnamed: R22.1, R23.2, SJ9.1, U3.5
unnamed: R21.2, R25.1, SJ7.1, U3.9
unnamed: C7.1, U4.3
unnamed: C7.2, U4.4
unnamed: R31.1, R32.2, SJ12.1, U4.5
unnamed: R30.2, R34.1, SJ10.1, U4.9
unnamed: C9.1, U5.3
unnamed: C9.2, U5.4
unnamed: R40.1, R41.2, SJ15.1, U5.5
unnamed: R39.2, R43.1, SJ13.1, U5.9
unnamed: C11.1, U6.3
unnamed: C11.2, U6.4
unnamed: R49.1, R50.2, SJ18.1, U6.5
unnamed: R48.2, R52.1, SJ16.1, U6.9
unnamed: C13.1, U7.3
unnamed: C13.2, U7.4
unnamed: R58.1, R59.2, SJ21.1, U7.5
unnamed: R57.2, R61.1, SJ19.1, U7.9
unnamed: C15.1, U8.3
unnamed: C15.2, U8.4
unnamed: R67.1, R68.2, SJ24.1, U8.5
unnamed: R66.2, R70.1, SJ22.1, U8.9
unnamed: C17.1, U9.3
unnamed: C17.2, U9.4
unnamed: R76.1, R77.2, SJ27.1, U9.5
unnamed: R75.2, R79.1, SJ25.1, U9.9
unnamed: C19.1, U10.3
unnamed: C19.2, U10.4
unnamed: R85.1, R86.2, SJ30.1, U10.5
unnamed: R84.2, R88.1, SJ28.1, U10.9
unnamed: C21.1, U11.3
unnamed: C21.2, U11.4
unnamed: R94.1, R95.2, SJ33.1, U11.5
unnamed: R93.2, R97.1, SJ31.1, U11.9
unnamed: C23.1, U12.3
unnamed: C23.2, U12.4
unnamed: R103.1, R104.2, SJ36.1, U12.5
unnamed: R102.2, R106.1, SJ34.1, U12.9
unnamed: C25.1, U13.3
unnamed: C25.2, U13.4
unnamed: R112.1, R113.2, SJ39.1, U13.5
unnamed: R111.2, R115.1, SJ37.1, U13.9
unnamed: C27.1, U14.3
unnamed: C27.2, U14.4
unnamed: R121.1, R122.2, SJ42.1, U14.5
unnamed: R120.2, R124.1, SJ40.1, U14.9
unnamed: C29.1, U15.3
unnamed: C29.2, U15.4
unnamed: R130.1, R131.2, SJ45.1, U15.5
unnamed: R129.2, R133.1, SJ43.1, U15.9
unnamed: C31.1, U16.3
unnamed: C31.2, U16.4
unnamed: R139.1, R140.2, SJ48.1, U16.5
unnamed: R138.2, R142.1, SJ46.1, U16.9
unnamed: C33.1, U17.3
unnamed: C33.2, U17.4
unnamed: R148.1, R149.2, SJ51.1, U17.5
unnamed: R147.2, R151.1, SJ49.1, U17.9
unnamed: C35.1, U18.3
unnamed: C35.2, U18.4
unnamed: R157.1, R158.2, SJ54.1, U18.5
unnamed: R156.2, R160.1, SJ52.1, U18.9
unnamed: C37.1, U19.3
unnamed: C37.2, U19.4
unnamed: R166.1, R167.2, SJ57.1, U19.5
unnamed: R165.2, R169.1, SJ55.1, U19.9
unnamed: C39.1, U20.3
unnamed: C39.2, U20.4
unnamed: R175.1, R176.2, SJ60.1, U20.5
unnamed: R174.2, R178.1, SJ58.1, U20.9
unnamed: C41.1, U21.3
unnamed: C41.2, U21.4
unnamed: R184.1, R185.2, SJ63.1, U21.5
unnamed: R183.2, R187.1, SJ61.1, U21.9
OUT: C1.1, JP3.2, R1.2, R2.P$2, U1.1, U1.8
OUT1: C4.1, JP7.2, R10.2, R17.P$2, U2.1, U2.8
OUT2: C6.1, JP11.2, R19.2, R26.P$2, U3.1, U3.8
OUT3: C8.1, JP15.2, R28.2, R35.P$2, U4.1, U4.8
OUT4: C10.1, JP19.2, R37.2, R44.P$2, U5.1, U5.8
OUT5: C12.1, JP23.2, R46.2, R53.P$2, U6.1, U6.8
OUT6: C14.1, JP27.2, R55.2, R62.P$2, U7.1, U7.8
OUT7: C16.1, JP31.2, R64.2, R71.P$2, U8.1, U8.8
OUT8: C18.1, JP35.2, R73.2, R80.P$2, U9.1, U9.8
OUT9: C20.1, JP39.2, R82.2, R89.P$2, U10.1, U10.8
OUT10: C22.1, JP43.2, R91.2, R98.P$2, U11.1, U11.8
OUT11: C24.1, JP47.2, R100.2, R107.P$2, U12.1, U12.8
OUT12: C26.1, JP51.2, R109.2, R116.P$2, U13.1, U13.8
OUT13: C28.1, JP55.2, R118.2, R125.P$2, U14.1, U14.8
OUT14: C30.1, JP59.2, R127.2, R134.P$2, U15.1, U15.8
OUT15: C32.1, JP63.2, R136.2, R143.P$2, U16.1, U16.8
OUT16: C34.1, JP67.2, R145.2, R152.P$2, U17.1, U17.8
OUT17: C36.1, JP71.2, R154.2, R161.P$2, U18.1, U18.8
OUT18: C38.1, JP75.2, R163.2, R170.P$2, U19.1, U19.8
OUT19: C40.1, JP79.2, R172.2, R179.P$2, U20.1, U20.8
OUT20: C42.1, JP83.2, R181.2, R188.P$2, U21.1, U21.8
POL: JP4.3, R7.1, U1.6
POL1: JP8.3, R15.1, U2.6
POL2: JP12.3, R24.1, U3.6
POL3: JP16.3, R33.1, U4.6
POL4: JP20.3, R42.1, U5.6
POL5: JP24.3, R51.1, U6.6
POL6: JP28.3, R60.1, U7.6
POL7: JP32.3, R69.1, U8.6
POL8: JP36.3, R78.1, U9.6
POL9: JP40.3, R87.1, U10.6
POL10: JP44.3, R96.1, U11.6
POL11: JP48.3, R105.1, U12.6
POL12: JP52.3, R114.1, U13.6
POL13: JP56.3, R123.1, U14.6
POL14: JP60.3, R132.1, U15.6
POL15: JP64.3, R141.1, U16.6
POL16: JP68.3, R150.1, U17.6
POL17: JP72.3, R159.1, U18.6
POL18: JP76.3, R168.1, U19.6
POL19: JP80.3, R177.1, U20.6
POL20: JP84.3, R186.1, U21.6
VIO: JP4.1, R5.2, R7.2, R9.2
VIO1: JP8.1, R11.2, R15.2, R18.2
VIO2: JP12.1, R20.2, R24.2, R27.2
VIO3: JP16.1, R29.2, R33.2, R36.2
VIO4: JP20.1, R38.2, R42.2, R45.2
VIO5: JP24.1, R47.2, R51.2, R54.2
VIO6: JP28.1, R56.2, R60.2, R63.2
VIO7: JP32.1, R65.2, R69.2, R72.2
VIO8: JP36.1, R74.2, R78.2, R81.2
VIO9: JP40.1, R83.2, R87.2, R90.2
VIO10: JP44.1, R92.2, R96.2, R99.2
VIO11: JP48.1, R101.2, R105.2, R108.2
VIO12: JP52.1, R110.2, R114.2, R117.2
VIO13: JP56.1, R119.2, R123.2, R126.2
VIO14: JP60.1, R128.2, R132.2, R135.2
VIO15: JP64.1, R137.2, R141.2, R144.2
VIO16: JP68.1, R146.2, R150.2, R153.2
VIO17: JP72.1, R155.2, R159.2, R162.2
VIO18: JP76.1, R164.2, R168.2, R171.2
VIO19: JP80.1, R173.2, R177.2, R180.2
VIO20: JP84.1, R182.2, R186.2, R189.2

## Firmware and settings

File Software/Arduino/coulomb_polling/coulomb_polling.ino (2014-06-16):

/* LTC4150 Coulomb Counter no-interrupt example code
Mike Grusin, SparkFun Electronics

This sketch shows how to use the LTC4150 Coulomb Counter breakout
board to implement a battery "gas gauge" without using interrupts.

Product page: https://www.sparkfun.com/products/12052
Software repository: https://github.com/sparkfun/LTC4150_Coulomb_Counter_BOB

HOW IT WORKS:

Battery capacity is measured in amp-hours (Ah). For example, a one
amp-hour battery can provide 1 amp of current for one hour, or 2 amps
for half an hour, or half an amp for two hours, etc.

The LTC4150 monitors current passing into or out of a battery.
It has an output called INT (interrupt) that will pulse low every
time 0.0001707 amp-hours passes through the part. Or to put it
another way, the INT signal will pulse 5859 times for one amp-hour.

If you hook up a full 1Ah (1000mAh) battery to the LTC4150, you
can expect to get 5859 pulses before it's depleted. If you keep track
of these pulses, you can accurately determine the remaining battery
capacity.

There is also a POL (polarity) signal coming out of the LTC4150.
When you detect a pulse, you can check the POL signal to see whether
current is moving into or out of the battery. If POL is low, current is
coming out of the battery (discharging). If POL is high, current is
going into the battery (charging).

(Note that because of chemical inefficiencies, it takes a bit more current
to charge a battery than you will eventually get out of it. This sketch
does not take this into account. For better accuracy you might provide
a method to "zero" a full battery, either automatically or manually.)

Although it isn't the primary function of the part, you can also
measure the time between pulses to calculate current draw. At 1A
(the maximum allowed), INT will pulse every 0.6144 seconds, or
1.6275 Hz. Note that for low currents, pulses will be many seconds
apart, so don't expect frequent updates.

There are two methods you can use to keep track of the INT pulses. You
can use an interrupt input to monitor the INT signal in the background,
or you can monitor the INT line yourself and use the CLR signal to reset
the LTC4150 for the next pulse.

** This sketch shows how to operate the LTC4150 without interrupts **

HARDWARE CONNECTIONS:

Before connecting this board to your Arduino, double check that
all three solder jumpers are set appropriately.

For this sketch, unsolder (open) SJ1.
This disconnects INT and CLR to allow you to use the CLR signal manually.

If you're using a 5V Arduino, leave both SJ2 and SJ3 open (unsoldered).

If you're using a 3.3V Arduino, close (solder) both SJ2 and SJ3.

Connect the following pins to your Arduino:

VIO to VCC
GND to GND
INT to D3
POL to D4
CLR to D6

Note that if you solder headers to the bottom of the board,
you can plug the breakout board directly into Arduino header
pins D2 (VIO) through D7 (SHDN).

RUNNING THE SKETCH:

This sketch monitors current moving into and out of a battery.
Whenever it detects a low INT signal from the LTC4150, it will
clear INT by making the CLR pin low, update the battery state-
of-charge (how full the battery is), current draw, etc.

The sketch is hardcoded for a 2000mAh battery that is 100% full
when the sketch starts. You can easily change this by editing
the following lines:

  double battery_mAh = 2000.0; // milliamp-hours (mAh)
  double battery_percent = 100.0;  // state-of-charge (percent)

After uploading the sketch, open the Serial Monitor and set the
baud rate to 9600. Whenever the sketch detects an INT pulse, it
will update its calculations and print them out.

LICENSE:

Our example code uses the "beerware" license. You can do anything
you like with this code. No really, anything. If you find it useful
and you meet one of us in person someday, consider buying us a beer.

Have fun! -Your friends at SparkFun.
*/

// For this sketch you only need the first five of the 
// following pins, but you can plug the board directly
// into the Arduino header (D2-D7) for convenience.

// (If you are not plugging the board directly into the
// header, you can remove all references to VIO, GND,
// and SHDN.)

#define VIO 2 // Just used for the HIGH reference voltage
#define INT 3
#define POL 4
#define GND 5 // Just used for the LOW reference voltage
#define CLR 6
#define SHDN 7 // Unneeded in this sketch, set to input

#define LED 13 // Standard Arduino LED

// Change the following two lines to match your battery
// and its initial state-of-charge:

double battery_mAh = 2000.0; // milliamp-hours (mAh)
double battery_percent = 100.0;  // state-of-charge (percent)

// Global variables:

double ah_quanta = 0.17067759; // mAh for each INT
double percent_quanta; // calculate below

void setup()
{
  // Set up I/O pins:
  
  pinMode(GND,OUTPUT);
  digitalWrite(GND,LOW);

  pinMode(VIO,OUTPUT);
  digitalWrite(VIO,HIGH);

  pinMode(INT,INPUT);

  pinMode(POL,INPUT);

  pinMode(CLR,OUTPUT);
  digitalWrite(CLR,HIGH);
  
  pinMode(SHDN,INPUT); // Unneeded, disabled by setting to input

  pinMode(LED,OUTPUT);
  digitalWrite(LED,LOW);  

  // Enable serial output:

  Serial.begin(9600);
  Serial.println("LTC4150 Coulomb Counter BOB no-interrupt example");

  // One INT is this many percent of battery capacity:
  
  percent_quanta = 1.0/(battery_mAh/1000.0*5859.0/100.0);
}

void loop()
{
  static long int time, lasttime;
  double mA;
  boolean polarity;

  if (digitalRead(INT)==0) // INT has gone low
  {
    // Determine delay since last interrupt (for mA calculation)
    // Note that first interrupt will be incorrect (no previous time!)

    lasttime = time;
    time = micros();

    // Get the polarity value
    
    polarity = digitalRead(POL);
    if (polarity) // high = charging
    {
      battery_mAh += ah_quanta;
      battery_percent += percent_quanta;
    }
    else // low = discharging
    {
      battery_mAh -= ah_quanta;
      battery_percent -= percent_quanta;
    }

    // Calculate mA from time delay (optional)
  
    mA = 614.4/((time-lasttime)/1000000.0);
  
    // If charging, we'll set mA negative (optional)
    
    if (polarity) mA = mA * -1.0;

    // Clear the interrupt signal

    digitalWrite(CLR,LOW);
    delayMicroseconds(40); // CLR needs to be low > 20us
    digitalWrite(CLR,HIGH);

    // Blink the LED (optional)
    
    digitalWrite(LED,HIGH);
    delay(100);
    digitalWrite(LED,LOW);

    // Print out the current battery status

    Serial.print("mAh: ");
    Serial.print(battery_mAh);
    Serial.print(" soc: ");
    Serial.print(battery_percent);
    Serial.print("% time: ");
    Serial.print((time-lasttime)/1000000.0);
    Serial.print("s mA: ");
    Serial.println(mA);
  }
}

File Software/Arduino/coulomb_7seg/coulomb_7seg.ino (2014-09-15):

/* LTC4150 Coulomb Counter 7-segment example code
Mike Grusin, SparkFun Electronics

This sketch uses the LTC4150 Coulomb Counter breakout
board to implement a battery "gas gauge" on a SparkFun
7-segment serial display. (We tried it on the OpenSegment Shield
but it should work on any similar display.) It will display the
percentage left on a battery based on how much power you're
pulling out of it.

The sketch assumes that you are starting with a full battery,
NOTE that you should change line 85 to enter the capacity
of the battery you are using.

COULOMB COUNTER HARDWARE CONNECTIONS:

Before connecting the Coulomb Counter to your Arduino, double
check that all three solder jumpers are set appropriately:

For this sketch, leave SJ1 soldered (closed).
This connects INT and CLR to clear interrupts automatically.

If you're using a 5V Arduino, leave both SJ2 and SJ3 open (unsoldered).

If you're using a 3.3V Arduino, close (solder) both SJ2 and SJ3.

Connect the following Coulomb Counter pins to your Arduino:

VIO to VCC
GND to GND
INT to D3
POL to D4

Note that if you solder headers to the breakout board,
you can plug it directly into Arduino header pins
D2 (VIO) through D7 (SHDN).

7-SEGMENT HARDWARE CONNECTIONS:

Connect the following serial 7-segment display pins to your Arduino:

VCC to VCC
GND to GND
RXI to D8

LICENSE:

Our example code uses the "beerware" license. You can do anything
you like with this code. No really, anything. If you find it useful
and you meet one of us in person someday, consider buying us a beer.

Have fun! -Your friends at SparkFun.
*/

// We'll use the SoftwareSerial library to talk to the serial
// 7-segment display. TX on pin 8 is compatible with the 
// 7 Segment Shield.

#include <SoftwareSerial.h>
SoftwareSerial Serial7Segment(7, 8); // RX pin, TX pin

// I/O pin definitions

// For this sketch we only need D3 and D4,
// but you can plug the board directly
// into the Arduino header (D2-D7) for convenience.

// (If you are not plugging the board directly into the
// header, you can remove all references to VIO, GND,
// CLR and SHDN.)

#define VIO 2 // Just used for the HIGH reference voltage
#define INT 3 // On 328 Arduinos, only pins 2 and 3 support interrupts
#define POL 4 // Polarity signal
#define GND 5 // Just used for the LOW reference voltage
#define CLR 6 // Unneeded in this sketch, set to input (hi-Z)
#define SHDN 7 // Unneeded in this sketch, set to input (hi-Z)

#define LED 13 // Standard Arduino LED (optional)
#define BUZZ 11 // Buzzer on pin 11 (optional)

// Change the following two lines to match YOUR battery
// and its initial state-of-charge:

volatile double battery_mAh = 110.0; // milliamp-hours (mAh)
volatile double battery_percent = 100.0;  // state-of-charge (percent)

// Global variables ("volatile" means the interrupt can
// change them behind the scenes):

volatile boolean isrflag;
volatile long int time, lasttime;
volatile double mA;
double ah_quanta = 0.17067759; // mAh for each INT
double percent_quanta; // calculate below

void setup()
{
  // Set up I/O pins:
  
  pinMode(GND,OUTPUT); // Make this pin LOW for "ground"
  digitalWrite(GND,LOW);

  pinMode(VIO,OUTPUT); // Make this pin HIGH for logic reference
  digitalWrite(VIO,HIGH);

  pinMode(INT,INPUT); // Interrupt input pin (must be D2 or D3)

  pinMode(POL,INPUT); // Polarity input pin

  pinMode(CLR,INPUT); // Unneeded, disabled by setting to input
  
  pinMode(SHDN,INPUT); // Unneeded, disabled by setting to input

  pinMode(LED,OUTPUT); // LED (optional)
  digitalWrite(LED,LOW);

  pinMode(BUZZ,OUTPUT); // Buzzer (optional)
  digitalWrite(BUZZ,LOW);

  // Set up serial 7-segment display

  Serial7Segment.begin(9600); // 9600 bps, TX on pin 8
  Serial7Segment.write('v');  // Reset the display

  // One INT is this many percent of battery capacity:
  
  percent_quanta = 1.0/(battery_mAh/1000.0*5859.0/100.0);

  // Enable active-low interrupts on D3 (INT1) to function myISR().
  // On 328 Arduinos, you may also use D2 (INT0), change '1' to '0'. 

  isrflag = false;
  attachInterrupt(1,myISR,FALLING);
}

void loop()
{
  // If an interrupt occurs (tick from the Coulomb Counter),
  // it will set isrflag to true to let us know that something
  // changed.

  if (isrflag)
  {
    // Clear the flag (so we only run this once per int)
    isrflag = false;
    
    // Send the updated percent value to 7-segment display
    print7SegFloat(battery_percent);

    // Blink LED and buzzer (optional)
    digitalWrite(LED,HIGH);
    tone(BUZZ,2000);

    delay(100);

    digitalWrite(LED,LOW);
    noTone(BUZZ);
  }
  
  // You can put anything else you want in the main loop,
  // just be sure you check for isrflag at least every
  // half-second (which is the highest frequency you'll see
  // at the 1A maximum current through the Coulomb Counter).
}

void myISR()// Run automatically for falling edge on D3 (INT1)
{
  static boolean polarity;
  
  // Determine delay since last interrupt (for mA calculation)
  // Note that first interrupt will be incorrect (no previous time!)

  lasttime = time;
  time = micros();

  // Get polarity value 

  polarity = digitalRead(POL);
  if (polarity) // high = charging
  {
    battery_mAh += ah_quanta;
    battery_percent += percent_quanta;
  }
  else // low = discharging
  {
    battery_mAh -= ah_quanta;
    battery_percent -= percent_quanta;
  }

  // Calculate mA from time delay (optional)

  mA = 614.4/((time-lasttime)/1000000.0);

  // If charging, we'll set mA negative (optional)
  
  if (polarity) mA = mA * -1.0;
  
  // Set isrflag so main loop knows an interrupt occurred
  
  isrflag = true;
}
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

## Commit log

2013-07-30 Ready for proto?
    [LTC4150 BOB V01.brd, LTC4150 BOB V01.sch, spreadsheet.ods]
2013-09-06 V02 ready for prototype
    [LTC4150 BOB.brd, LTC4150 BOB.sch, spreadsheet.ods]
2014-04-19 fixed silk error
    [LTC4150 BOB.brd]
2014-04-21 Final cleanup for reds
    [LTC4150 BOB.brd, LTC4150 BOB.sch]
2014-04-21 fixed resistor layout for 5V operation
    [LTC4150 BOB.brd, LTC4150 BOB.sch]
2014-05-01 Added initial example code
    [LTC4150 BOB.brd]
2014-05-02 Changed temp parts to SparkFun library variants
    [LTC4150 BOB.brd, LTC4150 BOB.sch]
2014-06-07 Rename and rearrange repository
    [LTC4150_BOB.brd, LTC4150_BOB.sch, spreadsheet.ods]
2014-06-07 Changed version to 1.0 for reds
    [LTC4150_BOB.brd, LTC4150_BOB.sch]
2014-06-11 Replaced solder jumper with pullup resistor
    [LTC4150_BOB.brd, LTC4150_BOB.sch]
2014-06-19 added board fiducials
    [LTC4150_BOB.brd, LTC4150_BOB.sch]
2014-06-19 created panel v10
    [LTC4150_BOB-Panel-v10.brd]
2014-09-11 updating code and tree
    [LTC4150_BOB.brd, spreadsheet.ods]
2020-05-22 Adjust folders to be case-sensitive
    [LTC4150_BOB.brd, LTC4150_BOB.sch, spreadsheet.ods]
2020-05-22 Delete spreadsheet.ods
    remove duplicate
    [spreadsheet.ods]
2020-05-22 Delete LTC4150_BOB.brd
    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
    [LTC4150_BOB.brd]
2020-05-22 Delete LTC4150_BOB.sch
    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
    [LTC4150_BOB.sch]

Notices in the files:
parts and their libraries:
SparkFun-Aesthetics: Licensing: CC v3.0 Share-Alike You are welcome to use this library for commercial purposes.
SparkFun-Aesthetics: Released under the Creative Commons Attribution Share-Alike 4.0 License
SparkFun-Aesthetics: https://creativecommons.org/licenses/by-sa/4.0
